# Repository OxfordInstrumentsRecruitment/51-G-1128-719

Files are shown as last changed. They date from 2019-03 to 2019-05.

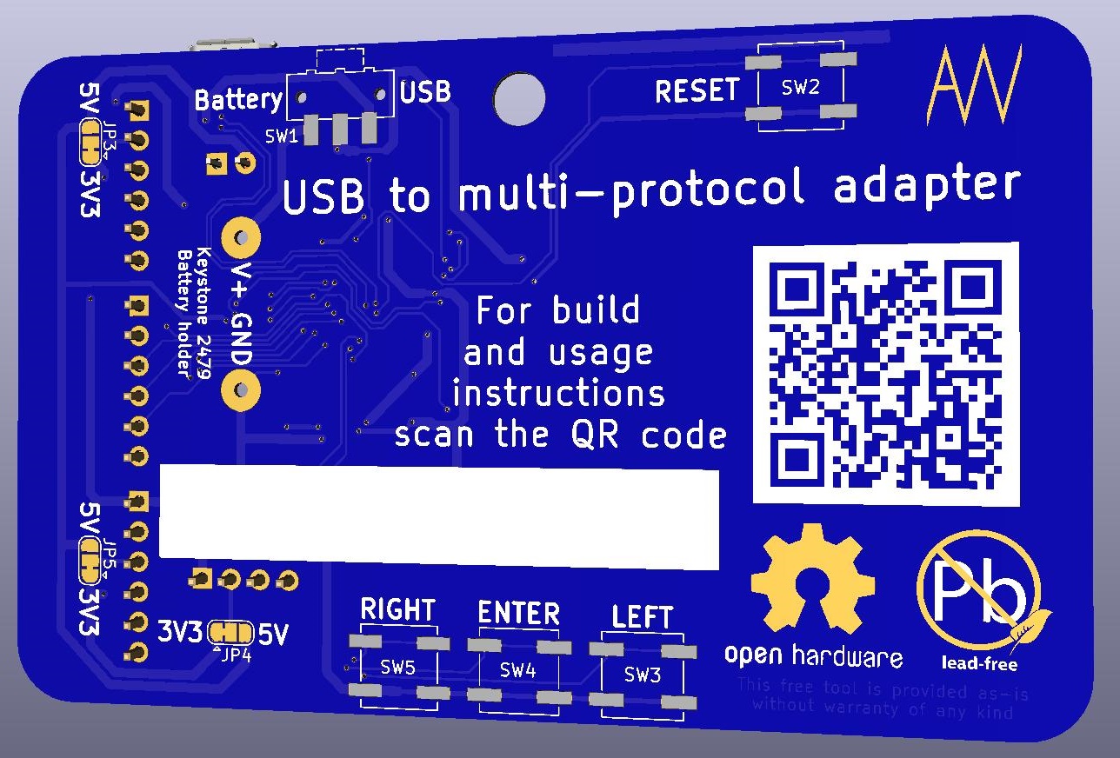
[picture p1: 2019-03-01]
Renders/Back_components.jpg

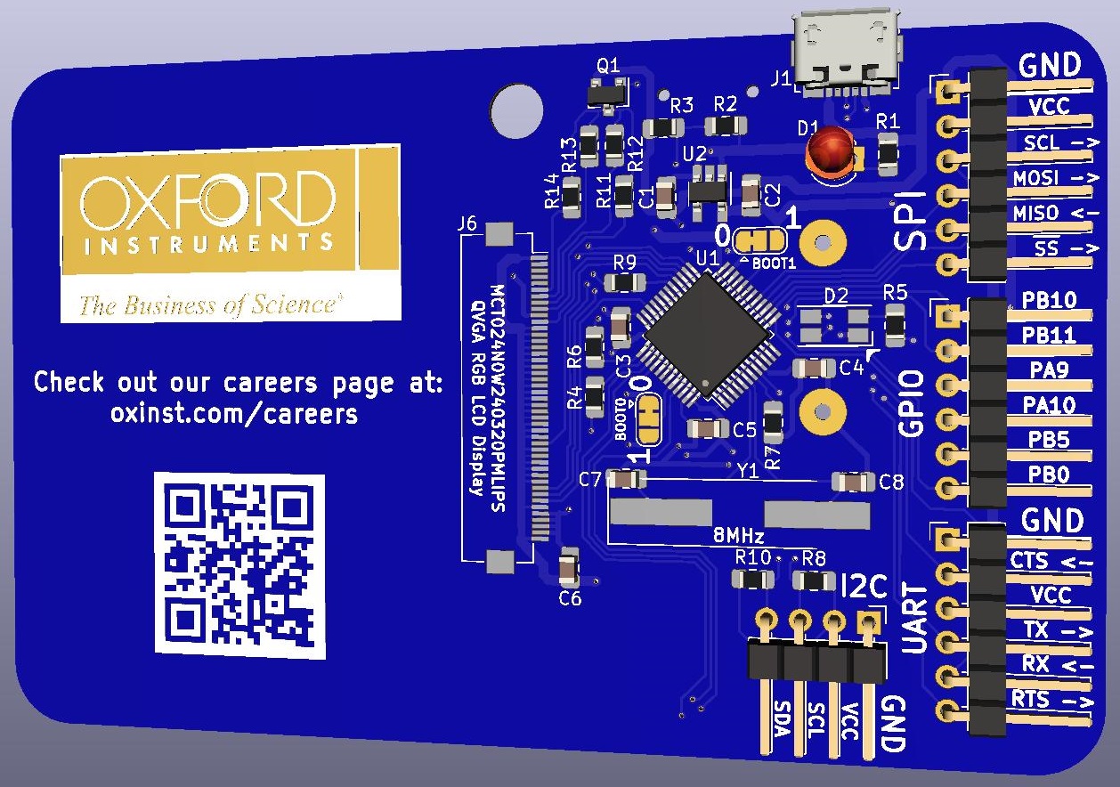
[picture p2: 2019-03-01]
Renders/Front_components.jpg

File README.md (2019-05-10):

# 51-G-1128-719
STM32F103 breakout board

This breakout board for the STM32F103 processor provides the following features:
* Compatible with the STM32duino framework
* A USB bootloader, allowing code to be loaded from the Arduino IDE
* A position for a 240x240 RGB screen based on the ST7789 controller
* An SD card reader
* Battery or USB operation
* A three button user interface
* An RGB LED with PWM brightness control
* SPI, UART, I2C, SWD and GPIO external connectivity

# Assembly Instructions

If you were given a blank PCB business card by someone from OI at an event and wish to populate and use it, you will need to follow the instructions in "PCB Business Card Assembly Instructions.PDF", which is in the Documentation folder. If your PCB business card was given to you with components already in place, you can skip this step, and skip programming the USB bootloader.

The assembly instructions document contains a list of the tools and consumables you will need to build this board. For a shopping list of components, check out the file "51-G-1128-719_BOM.xlsx" in the Documentation folder.

The BOM also links each component value to the corresponding reference designator on the PCB.

The display is available from a number of sources. A search for "4-wire SPI interface ST7789 1.3inch 240x240 RGB IPS" will return several listings. At the time of writing, the following listings are available:
* [Ebay from China, cheap but long lead time](https://www.ebay.co.uk/itm/1-3-Inch-Color-IPS-TFT-LCD-Display-Screen-Board-for-ST7789-12Pin-4-Line-Port-SPI/352645419739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)
* [Another Ebay listing](https://www.ebay.co.uk/itm/1-3-Inch-Color-IPS-TFT-LCD-Display-Screen-Board-for-ST7789-4-Line-12Pin-SPI-Port/273472845864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)
* [And another](https://www.ebay.co.uk/itm/4-wire-SPI-interface-ST7789-1-3inch-240-240Color-IPS-screen-LCD-module-12PIN/173349731176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)
* [Aliexpress from china, faster postage available](https://www.aliexpress.com/item/1pcs-New-IPS-1-3-inch-3-3V-SPI-interface-HD-Full-Color-TFT-Display-Screen/32904333824.html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,searchweb201602_10_10065_10130_10068_10547_319_317_10548_10696_10192_10190_453_10084_454_10083_10618_10307_10820_10301_10821_10303_537_536_10059_10884_10887_321_322_10103,searchweb201603_52,ppcSwitch_0&algo_expid=876473f1-1613-4a7e-939f-4c1f7fcc3143-1&algo_pvid=876473f1-1613-4a7e-939f-4c1f7fcc3143)
* [Another Aliexpress source](https://www.aliexpress.com/item/New-IPS-1-3-inch-3-3V-12PIN-SPI-HD-Full-Color-TFT-Display-Screen-ST7789/32859374478.html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)
* [And another](https://www.aliexpress.com/item/New-IPS-1-3-inch-3-3V-12PIN-SPI-HD-Full-Color-TFT-Display-Screen-ST7789/32953548434.html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)

# Programming The USB Bootloader

Once you have assembled your PCB business card, you must program the USB bootloader into the STM32F103 in order to use the Arduino IDE to program the device.

This is done using a USB to UART adapter such as the FTDI TTL-232R-3V3 or [equivalent](https://www.ebay.co.uk/sch/i.html?_from=R40&_trksid=m570.l1313&_nkw=usb+to+ttl+uart&_sacat=0). Follow these steps in order to program the bootloader:

* There is a solderable link near the SD card socket labelled "BOOT 0" - apply a bead of solder bridging the center to the side marked "1"
* Solder the RX, TX and GND signals from the USB to UART adapter to PA9, PA10 and GND on the PCB business card. PA9 and PA10 can be accessed via the GPIO pins on the right hand side of the PCB. When using an FTDI USB to UART cable, the orange wire goes to PA10 and the yellow wire goes to PA9.
* The exact programming procedure is slightly different on Windows, Linux and Mac. A Windows utility is provided to program the PCB in the Firmware\Bootloader\stm32tools\2019.2.28\win\ folder. The utility is called stm32flash.exe and runs stand alone with no installation required. The bootloader binary is "generic_boot20_pb9.bin" and can be found under the folder Firmware\Bootloader\. To use the provided utility on widnows:
  * Open a CMD window and navigate to Firmware\Bootloader\
  * Connect the USB to UART adapter and apply power to the PCB business card.
  * Determine the COM port number of the USB to UART adapter (this can be done from the Arduino IDE, or by opening device manager)
  * Then run the command (replacing the 3 in "COM3" with the COM port number on your system):
  `stm32tools\2019.2.28\win\stm32flash.exe -w generic_boot20_pb9.bin -v -g 0x0 COM3`
* If you are running Linux or Mac, follow the instructions on [this page of the STM32duino wiki](http://wiki.stm32duino.com/index.php?title=Burning_the_bootloader)
* Once the bootloader is programmed, remove power from the PCB business card and solder the "BOOT 0" link into the "0" position

# Uploading Your First Sketch

The PCB business card USB bootloader uses the standard windows DFU (Device Firmware Upload) driver, however the USB VID and PID are not known to Windows and therefore Windows will say "USB device not recognised" when you connect it. This problem can be solved by running the script "install_drivers.bat" in the folder: Firmware\drivers\win\

Once this is done, Windows should enumerate the PCB business card as a DFU capable device. This step is not required on Mac or Linux as both operating systems recognize the device as DFU capable and do not care about the VID and PID.

To program the example sketch onto the PCB card, follow these steps:

* Install the Arduino IDE
* Follow the instructions on [this page](http://wiki.stm32duino.com/index.php?title=Installation) to install the STM32duino extensions for the Arduino IDE
* copy the folders from Firmware\Libs\ into your Arduino Libraries folder.
* start the Arduino IDE (note that the IDE must not be open when you copy the library folders)
* open Firmware\Test\graphicstest\graphicstest.ino
* Select the correct COM port from the tools menu in the Arduino IDE
* Press the upload button

This sketch will display some test graphics. If you have an SD card, copy the contents of Firmware\Test\SD_Graphics\ onto it and put the SD card in the PCD business card. The card will now display some images from the card. The name on the name tag display comes from the file name.txt on the SD card. The logo on the same page comes from logo.bmp. The name must not be more than 13 characters. The job title must not be more than 20 characters. the logo must be 240 pixels wide and in uncompressed 24-bit bitmap format.

Up to 255 images can be added to the SD card with number names from 1.bmp to 255.bmp. Each will be displayed for 2 seconds.

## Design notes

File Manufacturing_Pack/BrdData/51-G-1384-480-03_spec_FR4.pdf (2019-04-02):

OINA Blank PCB Specification | DOCUMENT No. | 51-1720-202
| ISSUE No. | 1
| PAGE No. | 1 of 1

Oxford Instruments plc
NanoAnalysis
Halifax Road, High Wycombe Bucks., HP12 3SE, England
Tel: 44 (01494) 442255
www.oxford-instruments.com
This document is uncontrolled if printed. Refer to company network for latest issue.

The Business of Science®
- • •
PCB Part Number | 51-G-1384-480-03
Overall Size | 55 x 88 mm | Board extents | 55.0 x 88 mm
Overall Thickness | 0.6mm mm ±10%
Layers | 2
Substrate Material | FR4
Board surface Finish | Immersion Silver ☐ | Nickel/Gold ☑
Bare Board Test | Yes
Special Instructions/finishes IPC-A-600 Flammability FV-1 or IEC 60707
Release Status Required | None ☐ | C of C ☐ | UL94V-0 ☑ | ISO9000 ☑ | RoHS ☑
Finished board must be compatible with Lead-Free assembly.
Plated Holes | Unplated Holes
Sizes | Total | Min Hole Size | Sizes | Total | Min Hole Size
2 | 108 | 0.3 mm | 2 | 3 | 0.9mm
Track Details | Net/Pin Details
Min track width | Min track clearance | Number of Nets | Number of pins/pads
200 µm | 200 µm

Drill data file
| Specification | File
Plated | | PCB_Card-PTH.drl (gerber, PDF and post script also provided)
Plated Non Round
Non Plated | | PCB_Card-NPTH.drl (gerber, PDF and post script also provided)
Non-Plated Non Round
Layer Build | Specification | File name
Solder paste mask (top) | | PCB_Card-F.Paste.gbr
Silk (top) | White | PCB_Card-F.SilkS.gbr
Resist (top) | Blue | PCB_Card-F.Mask.gbr
Copper Layer 1 | 35µm (1oz) after plating | PCB_Card-F.Cu.gbr
Dielectric | FR4
Copper Layer 2 | 35µm (1oz) after plating | PCB_Card-B.Cu.gbr
Resist (bottom) | Blue | PCB_Card-B.Mask.gbr
Silk (bottom) | White | PCB_Card-B.SilkS.gbr
Solder paste mask (bottom) | None

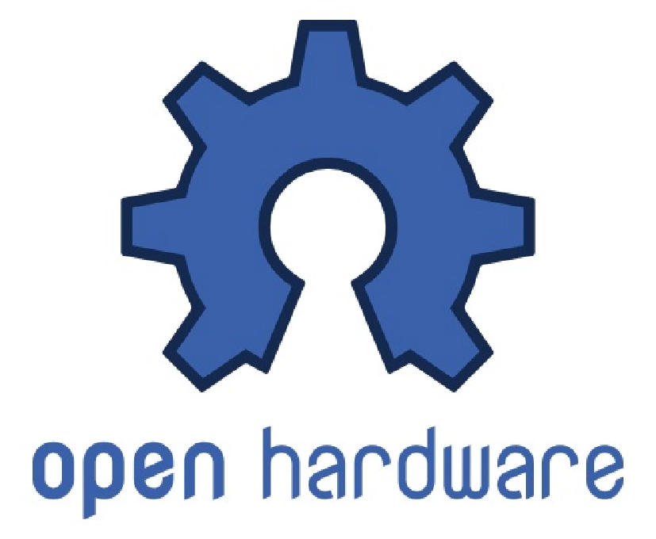
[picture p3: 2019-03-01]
KiCad_Project/PCB_Graphics/Open_Hardware/Open_Hardware.BMP

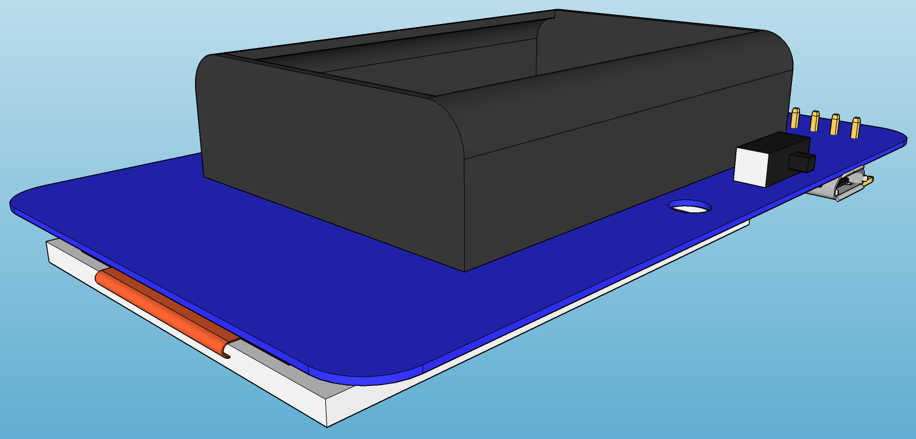
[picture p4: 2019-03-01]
Renders/3D_CAD_Back.png

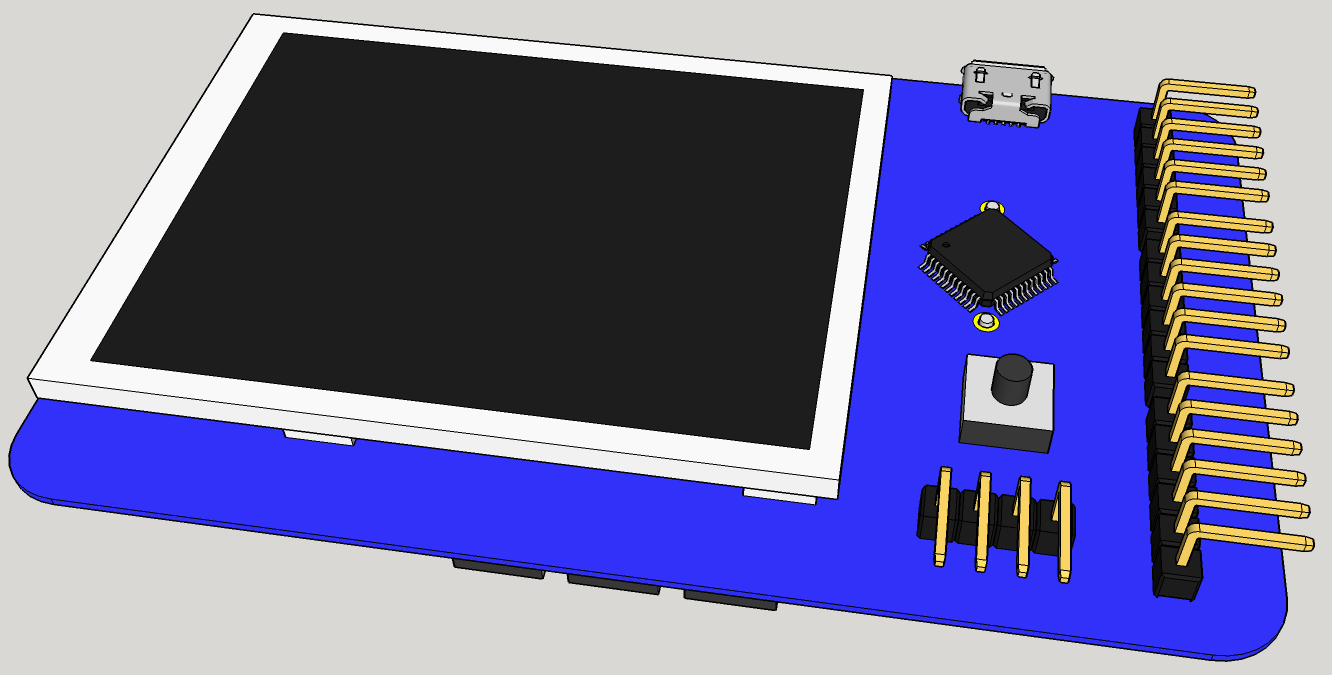
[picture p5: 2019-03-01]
Renders/3D_CAD_Top.png

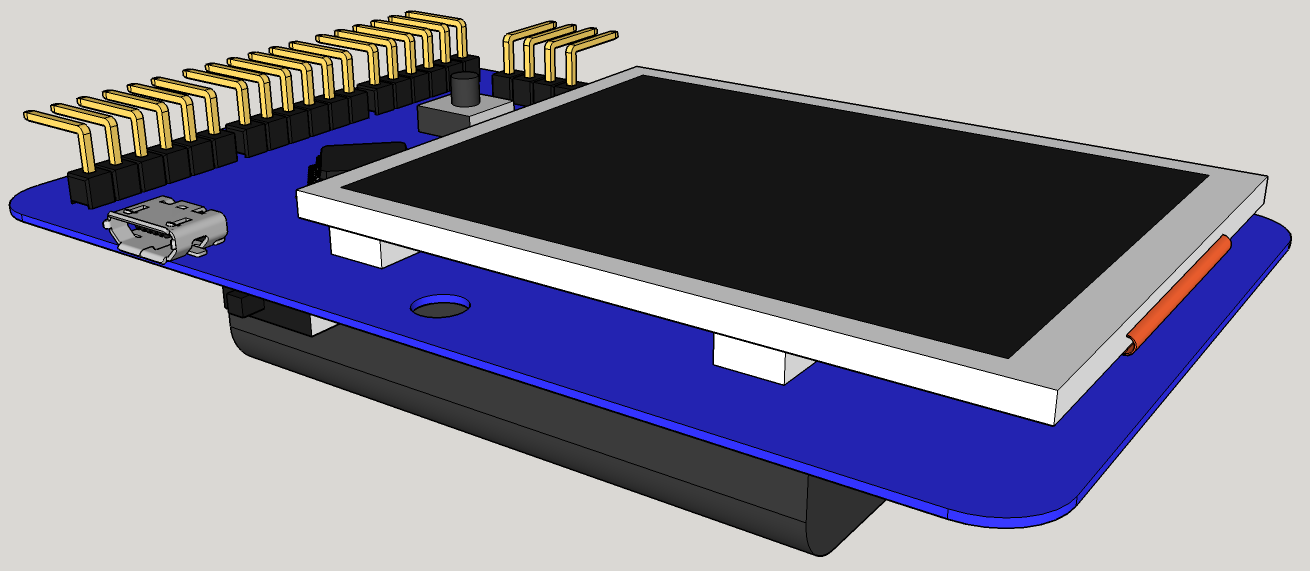
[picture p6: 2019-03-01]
Renders/3D_CAD_Edge.png

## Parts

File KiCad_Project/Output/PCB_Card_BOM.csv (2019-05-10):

Id | Designator | Package | Quantity | Designation | Supplier and ref
1 | J6 | 1.3_240x240_RGB_IPS_LCD | 1 | Conn_01x12_Female
2 | G*** | Oxford_Logo_35mm_Mask | 1 | LOGO
3 | G*** | Oxford_Logo_35mm_Copper | 1 | LOGO
4 | Y1 | Crystal_SMD_Abracon_ABM3-2Pin_5.0x3.2mm_HandSoldering | 1 | 8MHz
5 | BT1 | BatteryHolder_Keystone_2479_3xAAA | 1 | Battery
6 | G*** | SD_Logo_5mm_inv | 1 | LOGO
7 | JP1 | SolderJumper-3_P1.3mm_Open_RoundedPad1.0x1.5mm | 1 | BOOT0
8 | JP2 | SolderJumper-3_P1.3mm_Bridged12_RoundedPad1.0x1.5mm | 1 | BOOT1
9 | C4,C5,C3,C6,C9,C10,C11 | C_0805_2012Metric_Pad1.15x1.40mm_HandSolder | 7 | 100nF
10 | U1 | LQFP-48_7x7mm_P0.5mm | 1 | STM32F103C8Tx
11 | J10 | microSD_HC_Hirose_DM3AT-SF-PEJM5 | 1 | SD_Card
12 | G*** | ST32_Logo | 1 | LOGO
13 | R15,R1,R9 | R_0805_2012Metric_Pad1.15x1.40mm_HandSolder | 3 | 1K5
14 | SW1 | SW_SPDT_CK-JS102011SAQN | 1 | Power
15 | J3 | PinHeader_1x06_P2.54mm_Horizontal | 1 | GPIO
16 | C7,C8 | C_0805_2012Metric_Pad1.15x1.40mm_HandSolder | 2 | 18pF
17 | R8,R10 | R_0805_2012Metric_Pad1.15x1.40mm_HandSolder | 2 | 4K7
18 | D2 | LED_RGB_1210 | 1 | LED_RGB
19 | SW4 | SW_SPST_B3SL-1022P | 1 | ENTER
20 | C1,C2 | C_0805_2012Metric_Pad1.15x1.40mm_HandSolder | 2 | 1uF
21 | J1 | USB_Micro-B_Molex_47346-0001 | 1 | USB_B_Micro
22 | J2 | PinHeader_1x06_P2.54mm_Horizontal | 1 | EXT_SPI
23 | J4 | PinHeader_1x04_P2.54mm_Horizontal | 1 | EXT_I2C
24 | J5 | PinHeader_1x06_P2.54mm_Horizontal | 1 | EXT_UART
25 | JP3,JP4,JP5 | SolderJumper-3_P1.3mm_Bridged12_RoundedPad1.0x1.5mm | 3 | Voltage Select
26 | R2,R3,R7,R16,R17,R11 | R_0805_2012Metric_Pad1.15x1.40mm_HandSolder | 6 | 33K
27 | R4 | R_0805_2012Metric_Pad1.15x1.40mm_HandSolder | 1 | 22R
28 | R5 | R_0805_2012Metric_Pad1.15x1.40mm_HandSolder | 1 | 120R
29 | R6 | R_0805_2012Metric_Pad1.15x1.40mm_HandSolder | 1 | 16R
30 | SW2 | SW_SPST_B3SL-1022P | 1 | RESET
31 | SW3 | SW_SPST_B3SL-1022P | 1 | LEFT
32 | SW5 | SW_SPST_B3SL-1022P | 1 | RIGHT
33 | U2 | SOT-23-5_HandSoldering | 1 | MIC5504-3.3YM5
34 |  | MountingHole_4.3mm_M4 | 1 | MountingHole_4.3mm_M4
35 | G*** | github_link | 1 | LOGO
36 | G*** | OI_Careers_link | 1 | LOGO
37 | G*** | AW_Signature_7mm_inv | 1 | LOGO
38 | G*** | Open_Hardware | 1 | LOGO
39 | G*** | PB_Free_Ring | 1 | LOGO
40 | G*** | PB_Free_Text | 1 | LOGO
41 | J9 | PinHeader_1x05_P2.54mm_Horizontal | 1 | SWD
42 | G*** | ESD_Copper_8mm | 1 | LOGO
43 | G*** | ESD_Silk_8mm | 1 | LOGO
44 | D1 | LED_0805_2012Metric_Pad1.15x1.40mm_HandSolder | 1 | GREEN
45 | TP1,TP2,TP3,TP4,TP5,TP6 | TestPoint_Pad_D1.0mm | 6 | TestPoint
46 | TP7 | TestPoint_THTPad_D2.0mm_Drill1.0mm | 1 | TestPoint
47 | JP6 | SolderJumper-2_P1.3mm_Open_RoundedPad1.0x1.5mm | 1 | Jumper
48 | Q1 | SOT-23-6_Handsoldering | 1 | BC817DS
49 | R14 | R_0805_2012Metric_Pad1.15x1.40mm_HandSolder | 1 | 6R8
50 | TP8 | TestPoint_Pad_D3.0mm | 1 | +5V
51 | TP9 | TestPoint_Pad_D1.0mm | 1 | D+
52 | TP10 | TestPoint_Pad_D1.0mm | 1 | D-
53 | G*** | Oxford_Logo_35mm_Silk | 1 | LOGO

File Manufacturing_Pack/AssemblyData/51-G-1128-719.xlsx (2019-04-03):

51-G-1128-719 Bill of Materials
no | Description | Mfg PN | OI PN | Mouser PN | Farnell PN | Ref DES | DNP | Qty
1 | STM32 Microcontroller | STM32F103C8 | 51-G-1700-104 | 511-STM32F103C8T6 | 1447637 | U1 |  | 1
2 | 8 MHz Crystal 2 pin SMD 5x3.2mm 18pF load | ABM3-8.000MHZ-D2Y-T |  | ABM3-8.000MHZ-D2Y-T | 2101329 | Y1 |  | 1
3 | 3V3 300mA LDO regulator | MIC5504-3.3YM5-TR | 51-G-1306-094 | 998-MIC5504-3.3YM5TR | 2510377 | U2 |  | 1
4 | Micro USB B type connector | 47346-0001 | 51-G-1208-452 | 538-47346-0001 | 1568026 | J1 |  | 1
5 | 1uF MLCC Capacitor 0805 >=10V | Generic |  |  |  | C1,C2 |  | 2
6 | 100nF MLCC Capacitor 0805 >=10V | Generic |  |  |  | C4,C5,C3,C6,C9,C10,C11 |  | 7
7 | 18pF MLCC Capacitor 0805 >=10V | Generic |  |  |  | C7,C8 |  | 2
8 | 10Ω 0805 1% resistor | Generic |  |  |  | R14 |  | 1
9 | 1K5 0805 1% resistor | Generic |  |  |  | R15,R1,R9 |  | 3
10 | 4K7 0805 1% resistor | Generic |  |  |  | R8,R10 |  | 2
11 | 33K 0805 1% resistor | Generic |  |  |  | R2,R3,R7,R16,R17,R11 |  | 6
12 | 22Ω 0805 1% resistor | Generic |  |  |  | R4 |  | 1
13 | 120Ω 0805 1% resistor | Generic |  |  |  | R5 |  | 1
14 | 16Ω 0805 1% resistor | Generic |  |  |  | R6 |  | 1
15 | Dual NPN transistor | BC817DS |  | 771-BC817DS115 | 1757895 | Q1 |  | 1
16 | 0805 SMD LED Green | 150080VS75000 | 51-G-1252-087 | 710-150080VS75000 | 2322081 | D1 |  | 1
17 | RGB LED | 150121M153000 | 51-G-1252-089 | 710-150121M153000 | 2764968 | D2 |  | 1
18 | Micro SD card holder | DM3AT-SF-PEJM5 | 51-G-1716-094 | 798-DM3AT-SF-PEJM5 | 2427719 | J10 |  | 1
19 | Display | Free issue |  |  |  | J6 |  | 1
 | DNP Parts
20 | 6 way 2.54mm RA header | 826949-6 |  | 571-826949-6 | 1248180 | J2,J3,J5 | Y | 3
21 | 4 way 2.54mm RA header | 826947-4 |  | 571-826947-4 | 1248168 | J4 | Y | 1
22 | 5 way 2.54mm RA header | 826949-5 |  | 571-826949-5 | 1248179 | J9 | Y | 1
23 | SPST pushbutton switch | B3SL-1022P |  | 653-B3SL-1022P | 1695876 | SW2,SW3,SW4,SW5 | Y | 4
24 | 3x AAA battery holder | Keystone 2479 |  | 534-2479 | 1339843 | BT1 | Y | 1
25 | SPDT slide switch | JS102011SAQN |  | 611-JS102011SAQN | 2320017 | SW1 | Y | 1

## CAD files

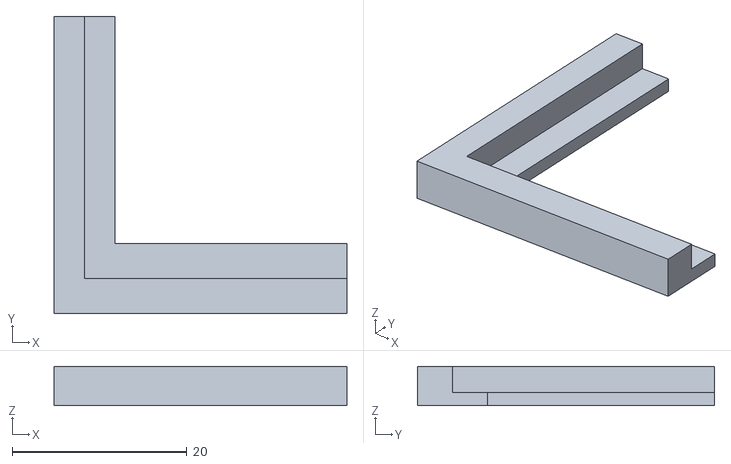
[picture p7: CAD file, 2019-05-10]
CAD/Screen_Alignment_Jig.stl
33.5 x 34.0 x 4.50

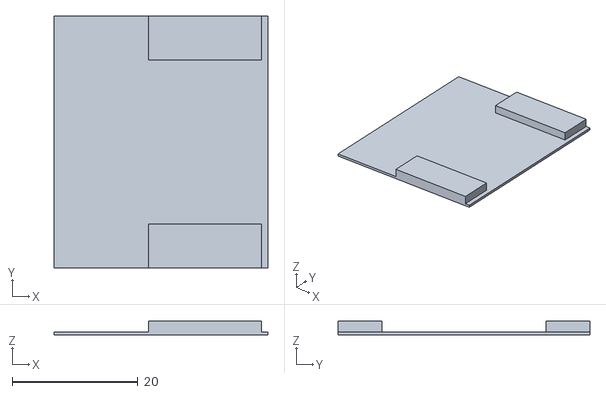
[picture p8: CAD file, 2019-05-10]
CAD/Screen_Support.stl
34.0 x 40.0 x 2.20

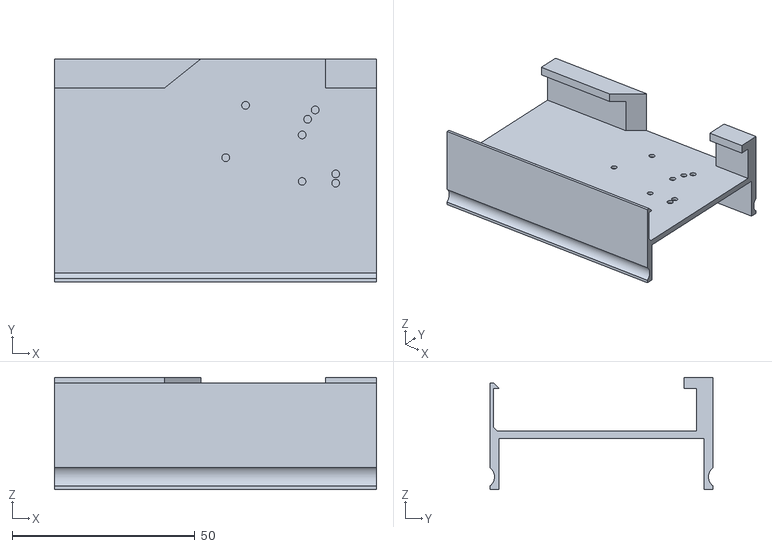
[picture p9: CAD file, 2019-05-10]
CAD/Programming_Jig.stl
88.0 x 61.0 x 30.7

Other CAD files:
CAD/PCB_Business_Card.skp
CAD/Programming_Jig.skp
CAD/Screen_Alignment_Jig.skp
CAD/Screen_Support.skp

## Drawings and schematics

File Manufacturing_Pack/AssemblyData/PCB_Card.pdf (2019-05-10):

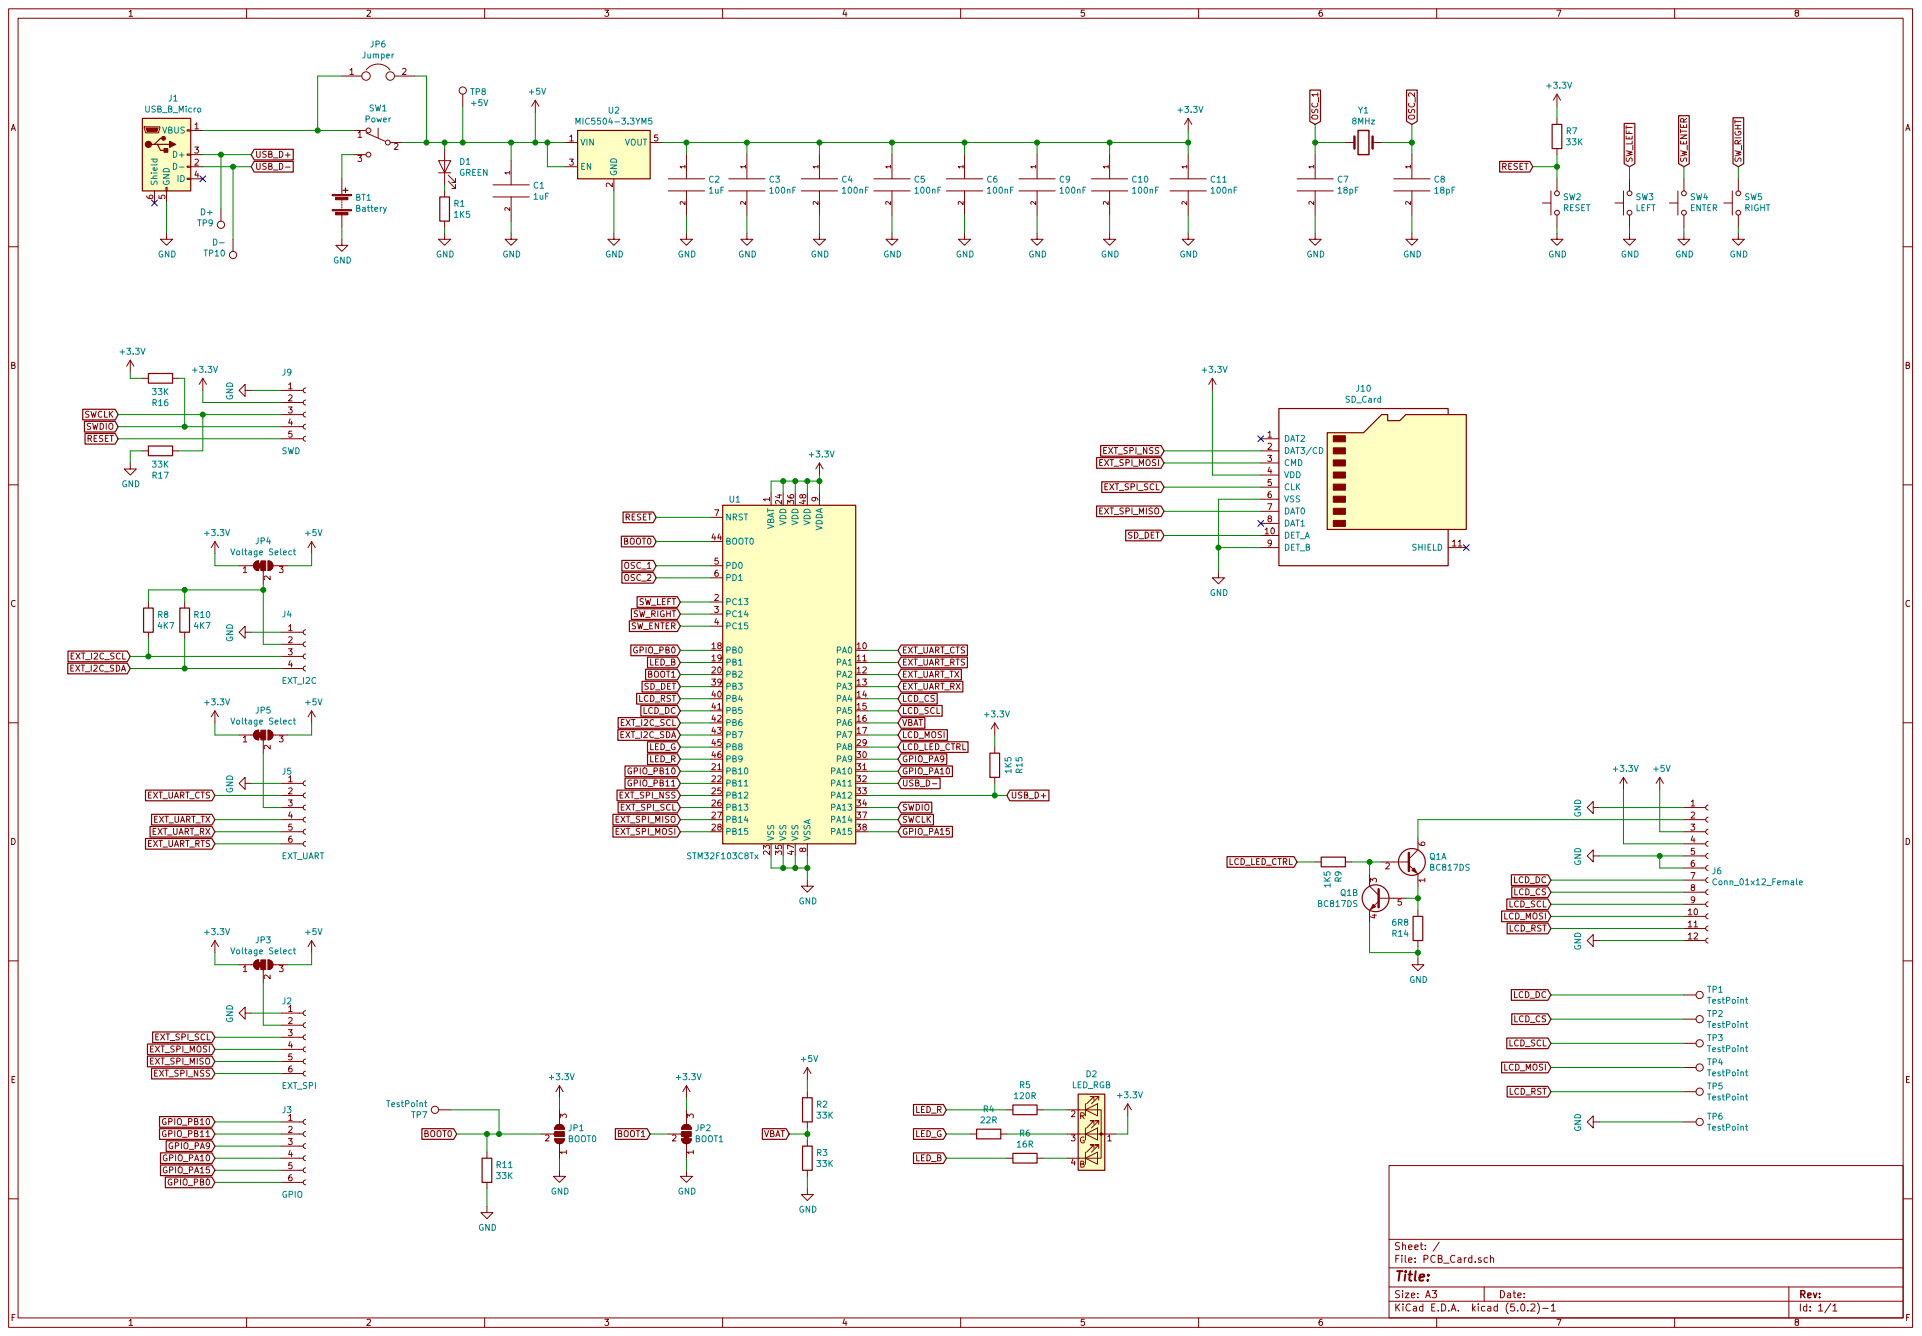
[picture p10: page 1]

1 VDD 24 VDD 36 VDD 48 VDDA

9 VSS 23 VSS 35 VSS 47 VSSA

TP1 TestPoint TP2 TestPoint TP3 TestPoint TP4 TestPoint TP5 TestPoint LCD_DC

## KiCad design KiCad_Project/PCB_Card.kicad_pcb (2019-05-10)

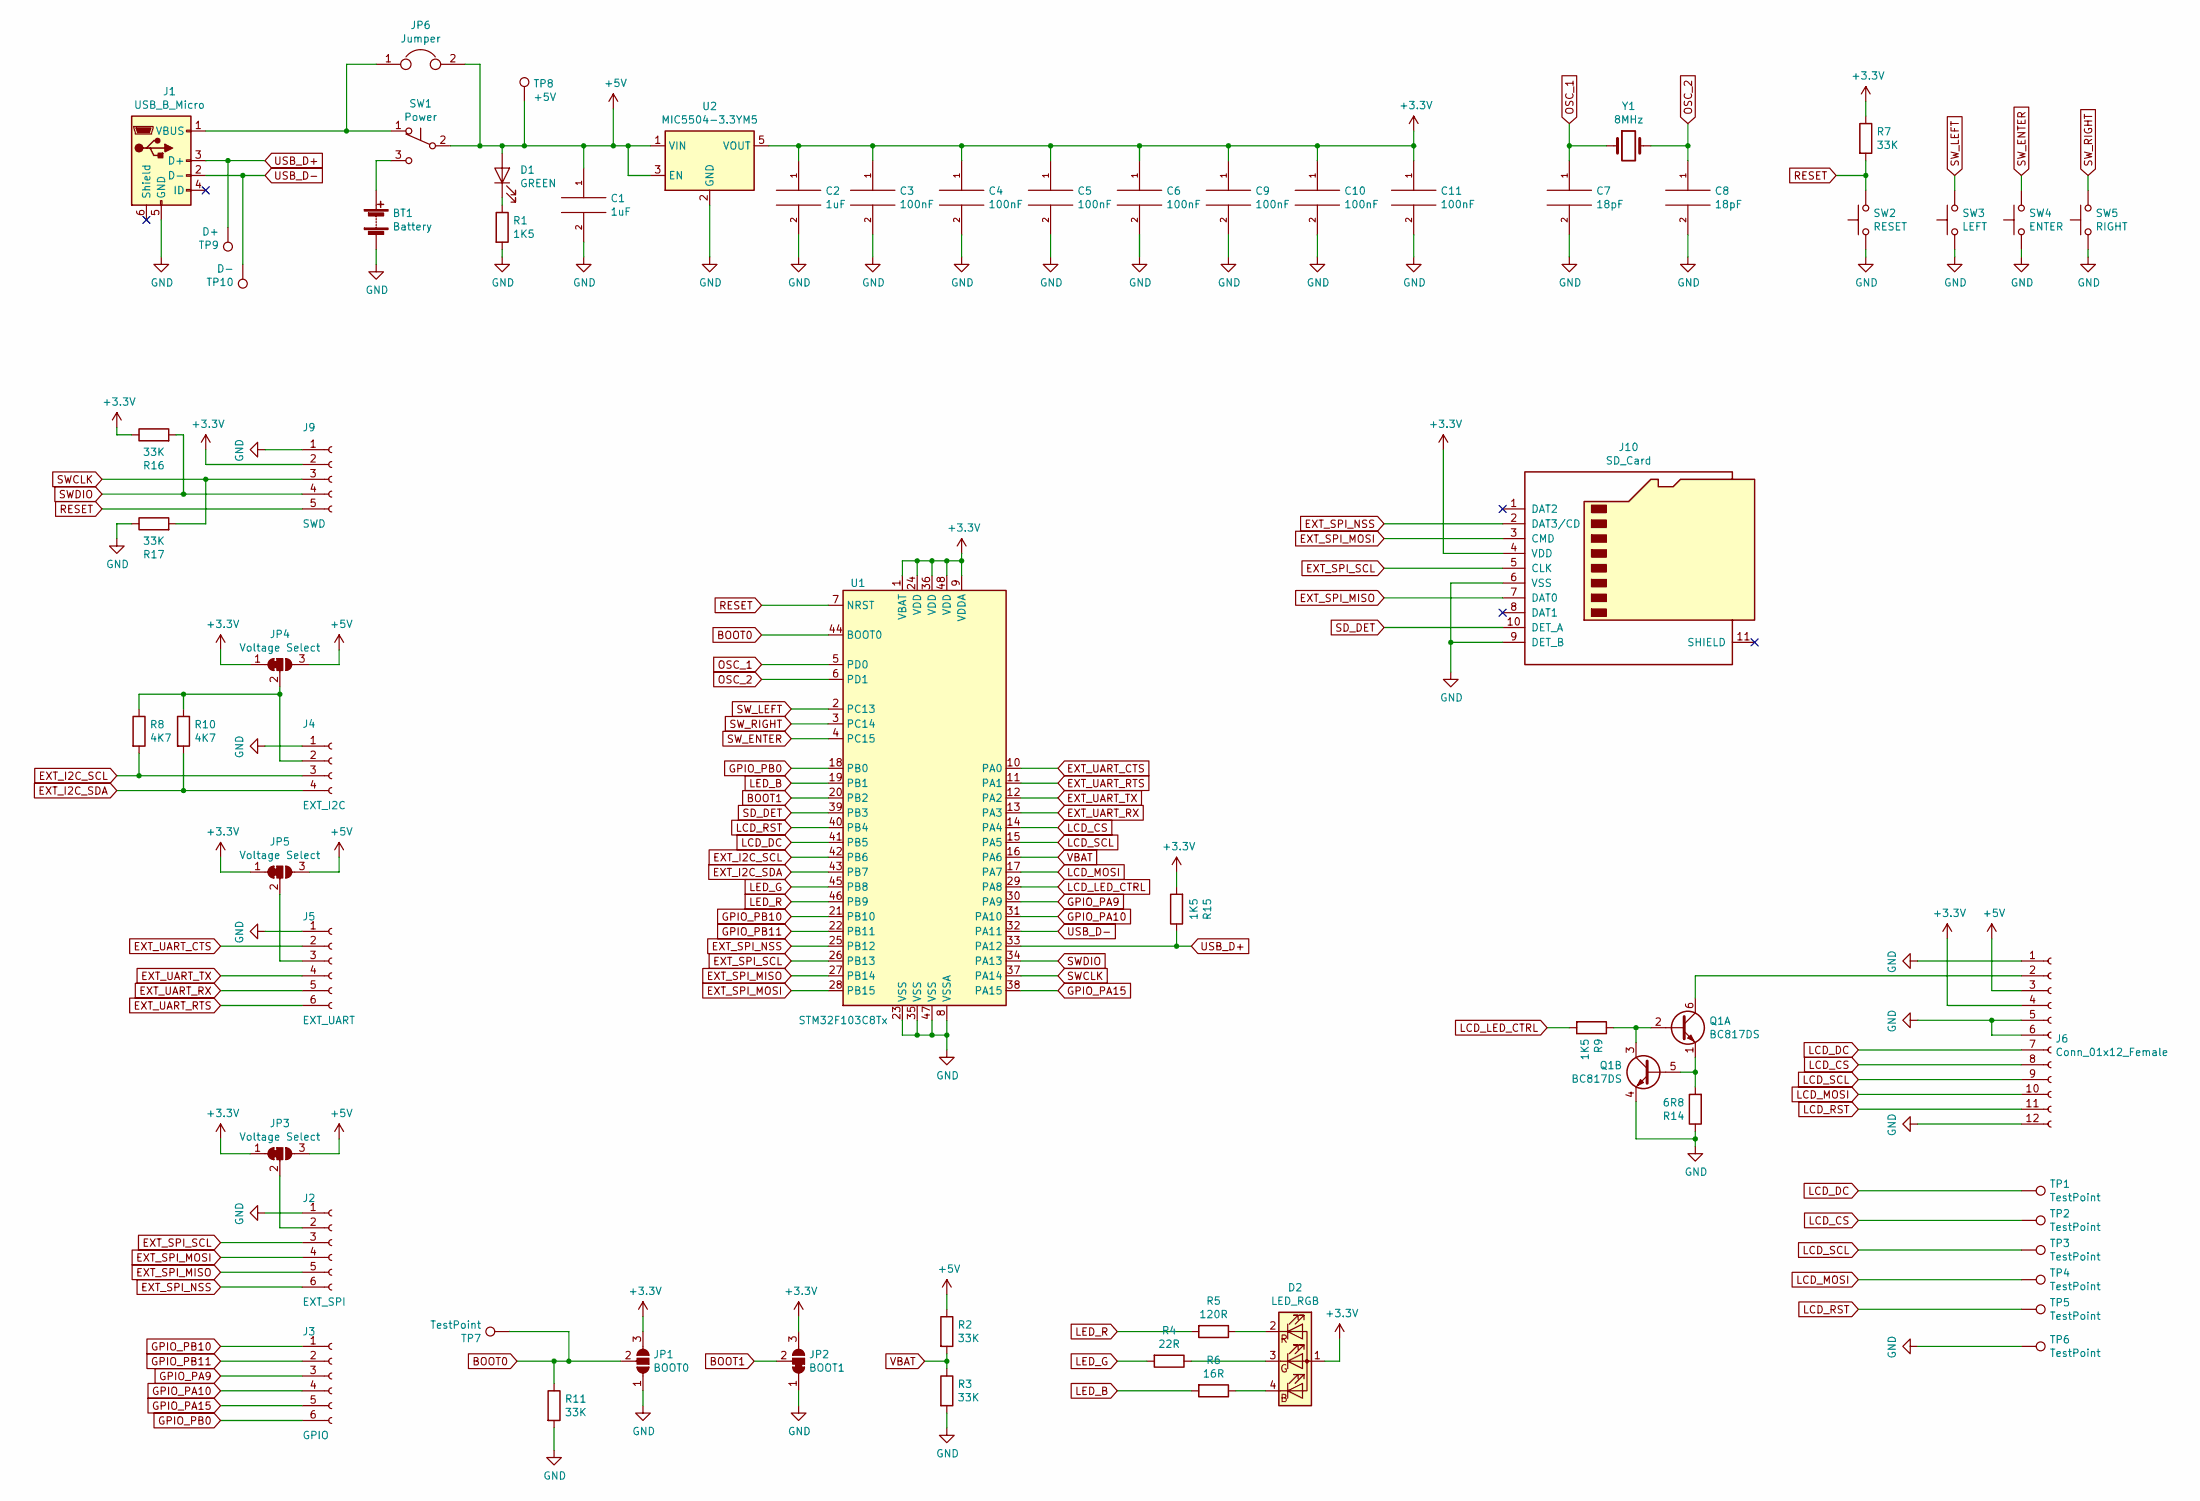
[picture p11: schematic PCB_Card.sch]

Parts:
BT1: Battery; BatteryHolder_Keystone_2479_3xAAA
C1, C2: 1uF; C_0805_2012Metric_Pad1.15x1.40mm_HandSolder
C3, C4, C5, C6, C9, C10, C11: 100nF; C_0805_2012Metric_Pad1.15x1.40mm_HandSolder
C7, C8: 18pF; C_0805_2012Metric_Pad1.15x1.40mm_HandSolder
D1: GREEN; LED_0805_2012Metric_Pad1.15x1.40mm_HandSolder
D2: LED_RGB; LED_RGB_1210
J1: USB_B_Micro; USB_Micro-B_Molex_47346-0001
J2: EXT_SPI; PinHeader_1x06_P2.54mm_Horizontal
J3: GPIO; PinHeader_1x06_P2.54mm_Horizontal
J4: EXT_I2C; PinHeader_1x04_P2.54mm_Horizontal
J5: EXT_UART; PinHeader_1x06_P2.54mm_Horizontal
J6: Conn_01x12_Female; 1.3_240x240_RGB_IPS_LCD
J9: SWD; PinHeader_1x05_P2.54mm_Horizontal
J10: SD_Card; microSD_HC_Hirose_DM3AT-SF-PEJM5
JP1: BOOT0; SolderJumper-3_P1.3mm_Open_RoundedPad1.0x1.5mm
JP2: BOOT1; SolderJumper-3_P1.3mm_Bridged12_RoundedPad1.0x1.5mm
JP3, JP4, JP5: Voltage Select; SolderJumper-3_P1.3mm_Bridged12_RoundedPad1.0x1.5mm
JP6: Jumper; SolderJumper-2_P1.3mm_Open_RoundedPad1.0x1.5mm
Q1: BC817DS; SOT-23-6_Handsoldering
R1, R9, R15: 1K5; R_0805_2012Metric_Pad1.15x1.40mm_HandSolder
R2, R3, R7, R11, R16, R17: 33K; R_0805_2012Metric_Pad1.15x1.40mm_HandSolder
R4: 22R; R_0805_2012Metric_Pad1.15x1.40mm_HandSolder
R5: 120R; R_0805_2012Metric_Pad1.15x1.40mm_HandSolder
R6: 16R; R_0805_2012Metric_Pad1.15x1.40mm_HandSolder
R8, R10: 4K7; R_0805_2012Metric_Pad1.15x1.40mm_HandSolder
R14: 6R8; R_0805_2012Metric_Pad1.15x1.40mm_HandSolder
SW1: Power; SW_SPDT_CK-JS102011SAQN
SW2: RESET; SW_SPST_B3SL-1022P
SW3: LEFT; SW_SPST_B3SL-1022P
SW4: ENTER; SW_SPST_B3SL-1022P
SW5: RIGHT; SW_SPST_B3SL-1022P
TP1, TP2, TP3, TP4, TP5, TP6: TestPoint; TestPoint_Pad_D1.0mm
TP7: TestPoint; TestPoint_THTPad_D2.0mm_Drill1.0mm
TP8: +5V; TestPoint_Pad_D3.0mm
TP9: D+; TestPoint_Pad_D1.0mm
TP10: D-; TestPoint_Pad_D1.0mm
U1: STM32F103C8Tx; LQFP-48_7x7mm_P0.5mm
U2: MIC5504-3.3YM5; SOT-23-5_HandSoldering
Y1: 8MHz; Crystal_SMD_Abracon_ABM3-2Pin_5.0x3.2mm_HandSoldering

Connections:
+3V3: C2.1, C3.1, C4.1, C5.1, C6.1, C9.1, C10.1, C11.1, D2.1 (A), J6.4, J9.2, J10.4 (VDD), JP1.3 (B), JP2.3 (B), JP3.1 (A), JP4.1 (A), JP5.1 (A), R7.1, R15.2, R16.1, U1.1 (VBAT), U1.9 (VDDA), U1.24 (VDD), U1.36 (VDD), U1.48 (VDD), U2.5 (VOUT)
+5V: C1.1, D1.2 (A), J6.3, JP3.3 (B), JP4.3 (B), JP5.3 (B), JP6.2, R2.1, SW1.2 (B), TP8.1, U2.1 (VIN), U2.3 (EN)
BOOT0: JP1.2 (C), R11.1, TP7.1, U1.44 (BOOT0)
BOOT1: JP2.2 (C), U1.20 (PB2)
EXT_I2C_SCL: J4.3, R8.2, U1.42 (PB6)
EXT_I2C_SDA: J4.4, R10.2, U1.43 (PB7)
EXT_SPI_MISO: J2.5, J10.7 (DAT0), U1.27 (PB14)
EXT_SPI_MOSI: J2.4, J10.3 (CMD), U1.28 (PB15)
EXT_SPI_NSS: J2.6, J10.2 (DAT3/CD), U1.25 (PB12)
EXT_SPI_SCL: J2.3, J10.5 (CLK), U1.26 (PB13)
EXT_UART_CTS: J5.2, U1.10 (PA0)
EXT_UART_RTS: J5.6, U1.11 (PA1)
EXT_UART_RX: J5.5, U1.13 (PA3)
EXT_UART_TX: J5.4, U1.12 (PA2)
GND: BT1.2 (-), C1.2, C2.2, C3.2, C4.2, C5.2, C6.2, C7.2, C8.2, C9.2, C10.2, C11.2, J1.5 (GND), J2.1, J4.1, J5.1, J6.1, J6.5, J6.6, J6.12, J9.1, J10.6 (VSS), J10.9 (DET_B), JP1.1 (A), JP2.1 (A), Q1.4 (E2), R1.2, R3.2, R11.2, R14.1, R17.1, SW2.1, SW3.1, SW4.1, SW5.1, TP6.1, U1.8 (VSSA), U1.23 (VSS), U1.35 (VSS), U1.47 (VSS), U2.2 (GND)
GPIO_PA9: J3.3, U1.30 (PA9)
GPIO_PA10: J3.4, U1.31 (PA10)
GPIO_PA15: J3.5, U1.38 (PA15)
GPIO_PB0: J3.6, U1.18 (PB0)
GPIO_PB10: J3.1, U1.21 (PB10)
GPIO_PB11: J3.2, U1.22 (PB11)
LCD_CS: J6.8, TP2.1, U1.14 (PA4)
LCD_DC: J6.7, TP1.1, U1.41 (PB5)
LCD_LED_CTRL: R9.2, U1.29 (PA8)
LCD_MOSI: J6.10, TP4.1, U1.17 (PA7)
LCD_RST: J6.11, TP5.1, U1.40 (PB4)
LCD_SCL: J6.9, TP3.1, U1.15 (PA5)
LED_B: R6.2, U1.19 (PB1)
LED_G: R4.2, U1.45 (PB8)
LED_R: R5.2, U1.46 (PB9)
unnamed: BT1.1 (+), SW1.3 (C)
unnamed: D1.1 (K), R1.1
unnamed: D2.2 (RK), R5.1
unnamed: D2.3 (GK), R4.1
unnamed: D2.4 (BK), R6.1
unnamed: J1.1 (VBUS), JP6.1, SW1.1 (A)
unnamed: J2.2, JP3.2 (C)
unnamed: J4.2, JP4.2 (C), R8.1, R10.1
unnamed: J5.3, JP5.2 (C)
unnamed: J6.2, Q1.6 (C1)
unnamed: Q1.1 (E1), Q1.5 (B2), R14.2
unnamed: Q1.2 (B1), Q1.3 (C2), R9.1
OSC_1: C7.1, U1.5 (PD0), Y1.1
OSC_2: C8.1, U1.6 (PD1), Y1.2
RESET: J9.5, R7.2, SW2.2, U1.7 (NRST)
SD_DET: J10.10 (DET_A), U1.39 (PB3)
SWCLK: J9.3, R17.2, U1.37 (PA14)
SWDIO: J9.4, R16.2, U1.34 (PA13)
SW_ENTER: SW4.2, U1.4 (PC15)
SW_LEFT: SW3.2, U1.2 (PC13)
SW_RIGHT: SW5.2, U1.3 (PC14)
USB_D+: J1.3 (D+), R15.1, TP9.1, U1.33 (PA12)
USB_D-: J1.2 (D-), TP10.1, U1.32 (PA11)
VBAT: R2.2, R3.1, U1.16 (PA6)

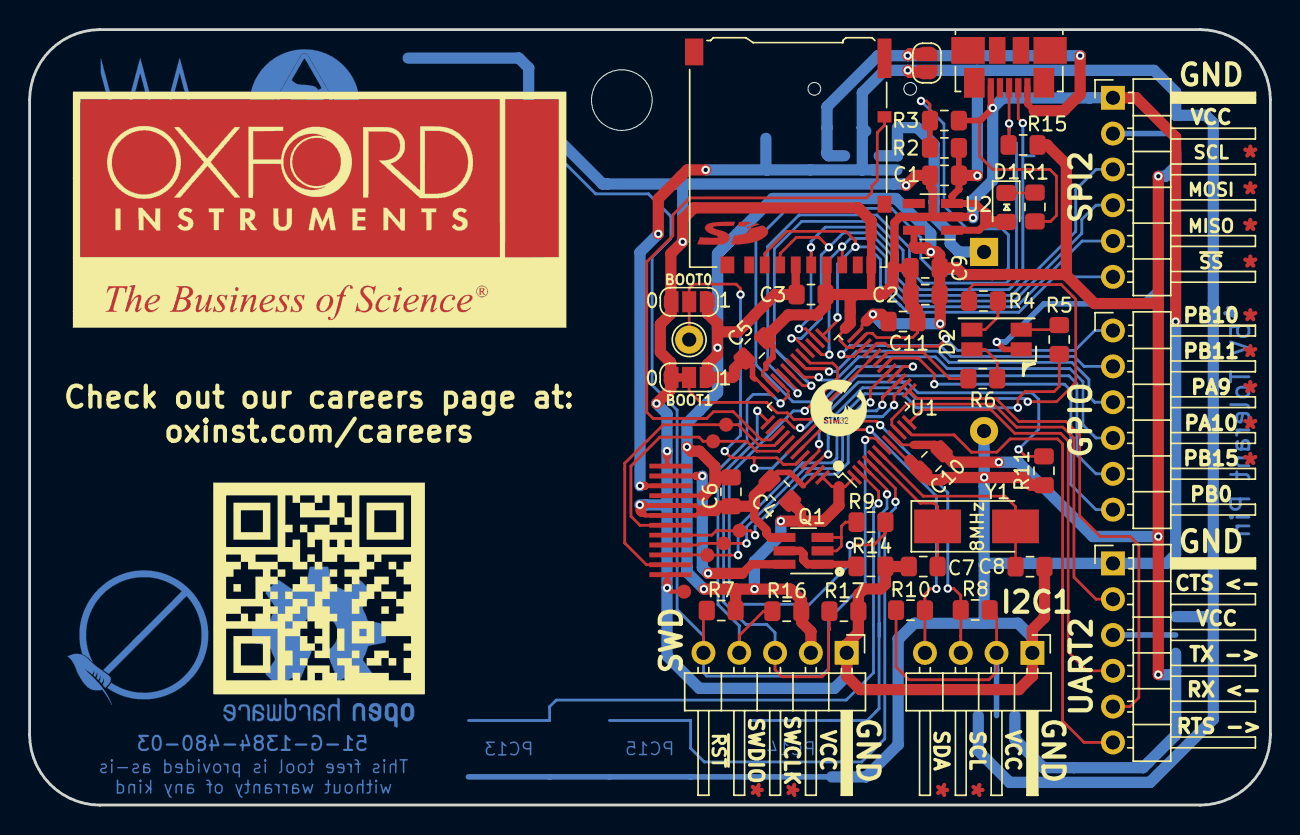
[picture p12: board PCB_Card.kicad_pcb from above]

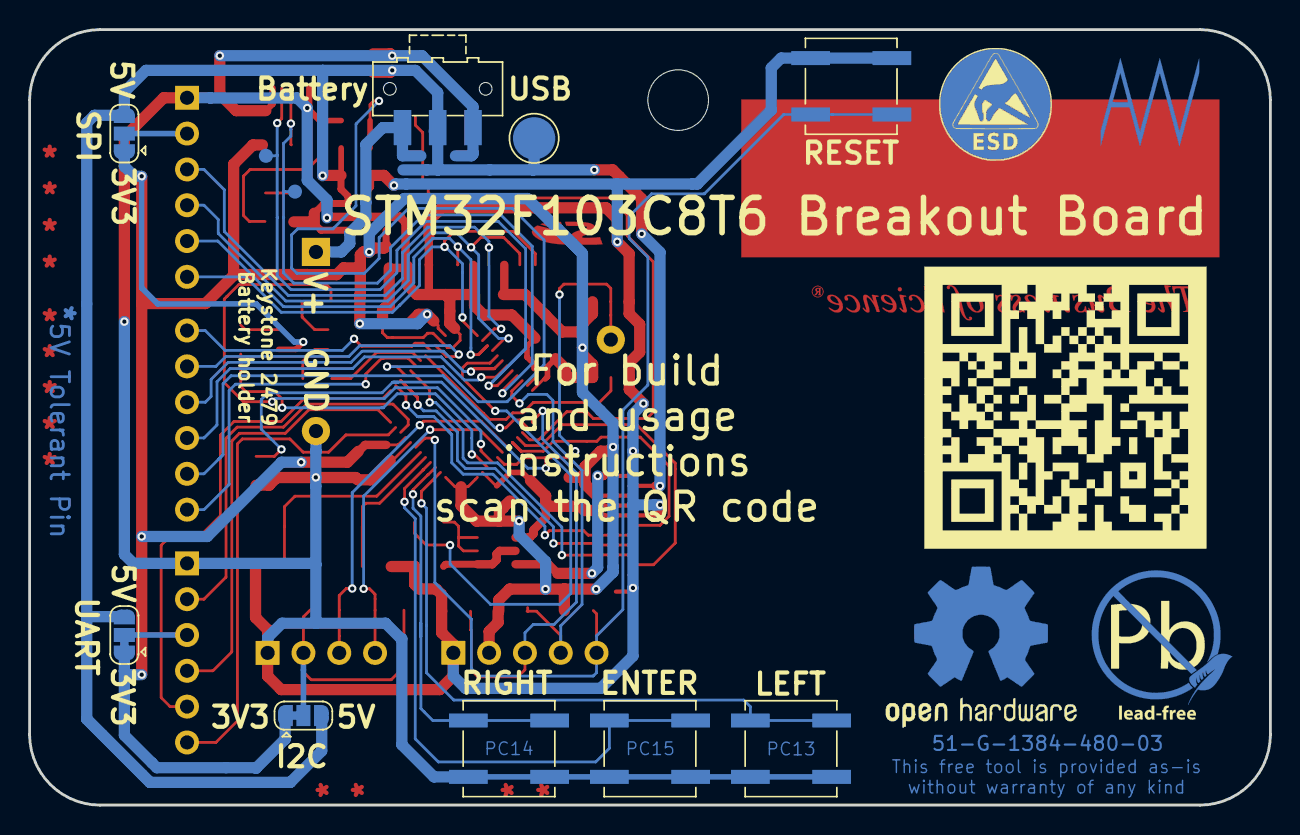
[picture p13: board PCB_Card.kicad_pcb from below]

Board: 2 copper layers, 88.0 x 55.0 mm, 62 parts (12 on the bottom side), 54 nets.

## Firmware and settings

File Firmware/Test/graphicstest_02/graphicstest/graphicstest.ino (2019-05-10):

#include <Adafruit_GFX.h>    // Core graphics library
#include <Adafruit_ST7789.h> // Hardware-specific library for ST7789
#include <SPI.h>
#include "SdFat.h"
#include "definitions.h"

// For 1.54" TFT with ST7789:
Adafruit_ST7789 tft = Adafruit_ST7789(TFT_CS, TFT_DC, TFT_RST);

//declare timer 1 object
HardwareTimer timer(1);

//SD card on SPI2
SPIClass SPI_2(2);
SdFat sd(&SPI_2);

uint8_t displayImage=0;
uint8_t displayStatus=STATUS_OK;
uint8_t schedState=SCHED_TAG;
bool SDPresent = false;
uint16_t LCDBrightness = LCD_DEFAULT_BRIGHTNESS;
char TagName[14] = "Alex Wood";
char TagPosition[21] = "Electronic Engineer";
File file;

void setup(void)
{
  //configure timer 1 to call an ISR every 10 milliseconds
  //used to drive the RGB led around its colour wheel
  //used to update LCD backlight
  //used to capture state of buttons and debounce
  timer.pause();
  timer.setPeriod(LED_RATE);
  timer.setChannel1Mode(TIMER_OUTPUT_COMPARE);
  timer.setCompare(TIMER_CH1, 1);  // Interrupt 1 count after each update
  timer.attachCompare1Interrupt(timer1_ISR);

  //init the display - fill with black before turning back light on
  tft.init(240, 240);           // Init ST7789 240x240
  tft.setRotation(3);
  tft.fillScreen(ST77XX_BLACK);
  pinMode(TFT_BACKLIGHT, OUTPUT);
  digitalWrite(TFT_BACKLIGHT, HIGH);
  //pinMode(TFT_BACKLIGHT, PWM);
  //pwmWrite(TFT_BACKLIGHT, LCDBrightness); // Backlight on at default brightness

  //set up the LED pins for open drain operation
  pinMode(LED_RED, PWM_OPEN_DRAIN);
  pinMode(LED_GREEN, PWM_OPEN_DRAIN);
  pinMode(LED_BLUE, PWM_OPEN_DRAIN);
  //turn the LEDs off for now
  analogWrite(LED_RED, 255);
  analogWrite(LED_GREEN, 255);
  analogWrite(LED_BLUE, 255);

  //SD card socket has a detect in
  pinMode(SD_DET, INPUT_PULLUP);
  
  //start timer 1
  timer.refresh();
  timer.resume();
}

void loop()
{
  //check for the SD card and initialise it if it is present
  checkSDCard();

  //Drive the scheduler state machine along (non-blocking)
  updateSchedule();

  //drive the display state machine along (non-blocking)
  updateDisplay();
}

void checkSDCard(void)
{
  //check for the SD card and initialise it if it is present
  if(digitalRead(SD_DET) == 0)
  {
    if(SDPresent==false)
    {
      if(sd.begin(SD_CS, SD_SCK_MHZ(50)))
      {
        SDPresent = true;

        //get the tag data from the card
        getTagData();
      }
    }
  }
  else
  {
    SDPresent = false;
  }
}

void getTagData(void)
{
  char temp;
  
  if(sd.exists("name.txt"))
  {
    file = sd.open("name.txt", FILE_READ);

    //grab the name from the file
    for(uint8_t i=0; i<14; i++)
    {
      temp = file.read();
      if(temp == '\r')
      {
        //reached the end of the name
        TagName[i] = 0;
        break;
      }
      else
      {
        TagName[i] = temp;
      }
    }

    //ensure there is a null terminator
    TagName[13] = 0;

    //if the name was longer than 13 characters, skip to the next line
    while(temp != '\r')
    {
      temp = file.read();
    }
    //skip over the LF is present
    if(file.peek() == '\n')
    {
      temp = file.read();
    }

    //grab the name from the file
    for(uint8_t i=0; i<21; i++)
    {
      temp = file.read();
      if(temp == '\r')
      {
        //reached the end of the name
        TagPosition[i] = 0;
        break;
      }
      else
      {
        TagPosition[i] = temp;
      }
    }

    //ensure there is a null terminator
    TagPosition[21] = 0;
  }
}

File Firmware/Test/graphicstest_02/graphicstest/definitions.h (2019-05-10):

#ifndef DEFINITIONS
#define DEFINITIONS

//display state machine states
enum
{
  DISPLAYSTATE_NONE,
  DISPLAYSTATE_BLACK,
  DISPLAYSTATE_TAG,
  DISPLAYSTATE_IMAGE,
  DISPLAYSTATE_LORUM,
  DISPLAYSTATE_PRINT,
  DISPLAYSTATE_LINES,
  DISPLAYSTATE_RECT,
  DISPLAYSTATE_FILLRECT,
  DISPLAYSTATE_CIRCLES,
  DISPLAYSTATE_TRIANGLES,
};

//general purpose return states
enum
{
  STATUS_OK,
  STATUS_ERROR,
  STATUS_NOFILE,
  STATUS_NOSD,
  STATUS_FORMATERR,
};

//scheduler states
enum
{
  SCHED_STOPPED,
  SCHED_ARMED,
  SCHED_TRIGGERED,
  SCHED_WAIT,
  SCHED_TAG,
  SCHED_IMG,
  SCHED_PRINT,
  SCHED_LINES,
  SCHED_FILLRECT,
  SCHED_TRIANGLES,
  SCHED_CIRCLES,
};



//pin definitions
#define TFT_CS        PA4
#define TFT_RST       PB4
#define TFT_DC        PB5
#define TFT_BACKLIGHT PA8
#define LED_RED       PB9
#define LED_GREEN     PB8
#define LED_BLUE      PB1
#define SD_DET        PB3
#define SW_LEFT       PC13
#define SW_RIGHT      PC14
#define SW_ENTER      PC15
#define SD_CS         PB12

#define WHEELPOSMAX   767
#define LED_RATE 10000    // in microseconds
#define LCD_DEFAULT_BRIGHTNESS 65535


//------------------------------------------------------------------------------
// print error msg, any SD error codes, and halt.
// store messages in flash
#define errorExit(msg) errorHalt(F(msg))
#define initError(msg) initErrorHalt(F(msg))
//------------------------------------------------------------------------------

#endif

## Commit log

2019-03-01 Added kikad project
    [PCB_Card-B.Cu.gbr, PCB_Card-B.Fab.gbr, PCB_Card-B.Mask.gbr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]
2019-03-01 Added manufacturing pack
    [51-G-1128-719_BOM.xlsx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]
2019-03-29 Added documentation
    [51-G-1128-719_BOM.xlsx, MCU_Pin_Allocation.xlsx]
2019-04-02 Updated to latest PCB CAD (revision 3)
    [PCB_Card-B.Cu.gbr, PCB_Card-B.Fab.gbr, PCB_Card-B.Mask.gbr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]
2019-04-02 Updated manufacturing pack to latest version (R3)
    [51-G-1128-719_BOM.xlsx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]
2019-04-03 Added instructions
    [51-G-1128-719_BOM.xlsx]
2019-05-10 Added software libs
    [PCB_Card-B.Cu.gbr, PCB_Card-B.Mask.gbr, PCB_Card-B.SilkS.gbr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]
2019-05-10 Updated PCB CAD
    Added 3D CAD of programming jig, screen alignment jig etc
    Added LT spice simulation of LED driver circuit
    [51-G-1128-719.xlsx, PCB_Business_Card.skp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]
